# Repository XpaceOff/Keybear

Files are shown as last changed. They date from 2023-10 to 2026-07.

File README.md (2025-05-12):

# Keybear

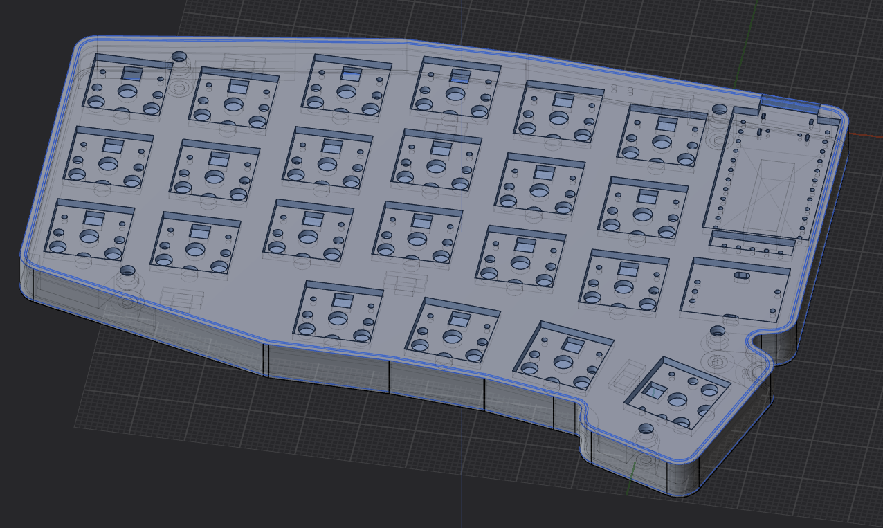
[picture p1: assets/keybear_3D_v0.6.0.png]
Keybear 3D Model


## Directory Structure

- firmware: contain files to setup the firmware of the board.
  - kmk: [kmk firmware](https://github.com/KMKfw/kmk_firmware) config files.
- keybear-chocolate: all files used to create the chocolate version of the board.
  - case:
    - gcode_and_obj: Files used to print the case
    - plasticity_archive: old versions of the plasticity file.
    - keybear-choco_case_slim.plasticity: Latest plasticity file.
- kicad_footprints: footprints used in my kicad projects.

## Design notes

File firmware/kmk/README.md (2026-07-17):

# Keybear KMK Firmware

This folder contains KMK firmware configurations for the Keybear keyboard.  
Each subfolder targets a specific microcontroller. The PCB and wiring are identical across all variants — only the controller and its pin names differ.

---

## PCB Pad Map

The pad numbers below refer to the physical pads on the Keybear PCB, following the standard Pro Micro pinout layout.

```
Pad 24 ── RAW              TX  ── Pad 1
Pad 23 ── GND              RX  ── Pad 2
Pad 22 ── RST              GND ── Pad 3
Pad 21 ── VCC              GND ── Pad 4
Pad 20 ── COL0             SDA ── Pad 5
Pad 19 ── COL1             SCL ── Pad 6
Pad 18 ── COL2             ROW0 ── Pad 7
Pad 17 ── COL3             ROW1 ── Pad 8
Pad 16 ── COL4             ROW2 ── Pad 9
Pad 15 ── COL5             ROW3 ── Pad 10
Pad 14 ── CS               ENCA ── Pad 11
Pad 13 ── LED              ENCB ── Pad 12
```

| Pad | Function | Notes |
|-----|---|---|
| 1 | TX | UART transmit — split comms |
| 2 | RX | UART receive — split comms |
| 3 | GND | |
| 4 | GND | |
| 5 | SDA | I2C data |
| 6 | SCL | I2C clock |
| 7 | ROW0 | Matrix row 0 |
| 8 | ROW1 | Matrix row 1 |
| 9 | ROW2 | Matrix row 2 |
| 10  | ROW3 | Matrix row 3 |
| 11  | ENCA | Rotary encoder pin A |
| 12  | ENCB | Rotary encoder pin B |
| 13  | LED | RGB data line |
| 14  | CS | |
| 15  | COL5 | Matrix column 5 |
| 16  | COL4 | Matrix column 4 |
| 17  | COL3 | Matrix column 3 |
| 18  | COL2 | Matrix column 2 |
| 19  | COL1 | Matrix column 1 |
| 20  | COL0 | Matrix column 0 |
| 21  | VCC | 3.3 V power |
| 22  | RST | Reset |
| 23  | GND | |
| 24  | RAW | Battery / unregulated power input |

---

## Controller Variants

| Folder | Controller | Split | BLE |
|---|---|---|-----|
| [`blok/`](blok/) | Boardsource BLOK (RP2040) | Wired UART | No |
| [`nice_nano/wired/`](nice_nano/wired/) | nice!nano v2 (nRF52840) | Wired UART | No |
| [`nice_nano/wireless/`](nice_nano/wireless/) | nice!nano v2 (nRF52840) | BLE | Yes |
| [`nice_nano/wired/mix/`](nice_nano/wired/mix/) | nice!nano (left) + BLOK (right) | Wired UART | No |

---

## BLOK Setup

- Install CircuitPython [v8.2.6](https://adafruit-circuit-python.s3.amazonaws.com/bin/boardsource_blok/en_US/adafruit-circuitpython-boardsource_blok-en_US-8.2.6.uf2)
- Get a KMK copy of this [commit 5525233](https://github.com/KMKfw/kmk_firmware/archive/5525233cb957c367e4f0b589abcaeb1b5da53ec0.zip)

For nice!nano variants see the README inside the relevant subfolder.

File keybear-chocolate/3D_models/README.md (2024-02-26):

Here are the *.step files I import into plasticity to then create the case.

The first time I did this, I can export the STEP file from Kicad directly
but last time I tried I had many issues with the format. If that fails then
you could use Freecad to export the STEP file. 

Here are the two ways to export the STEP file:

## From Kicad directly
Go to `File` > `Export` > `STEP...` and select this directory

## From Freecad
- Install Freecad.
- Install the plugin called `StepUp Workbench`. In Freecad go to `Tools` > `Addon Manager` and install it.
- Restart Freecad.
- Open the `*.kicad_pcb` file from Freecad.
- Select the PCB and export the STEP file by going to `File` > `Export...`.
When ask about export options make sure to set:
    - Units for export of STEP: Millimeter
    - Export single object placement.

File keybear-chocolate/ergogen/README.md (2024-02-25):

I downloaded Ergogen in a folder called `tmp` in the upper directory.

projects
  |-- tmp
  | |-- ergogen
  |-- Keybear

to compile the Kicad files from the Ergogen config file I do:

```bash
cd Keybear

# For PCB
node ..\tmp\ergogen\src\cli.js keybear-chocolate\ergogen\ -o keybear-chocolate\ergogen\out\PCB

# For Plate
node ..\tmp\ergogen\src\cli.js keybear-chocolate\ergogen\ -o keybear-chocolate\ergogen\out\Plate
```

> [!Note] 
> To generate the plate you will need to change the value of `pcbs.keybear.outlines.main.outline`
> to `combo`. Generate the plate and remember to set it back to `plate`

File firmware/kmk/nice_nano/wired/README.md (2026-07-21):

# Keybear — nice!nano v2 Wired Setup

This folder contains KMK firmware files for the Keybear keyboard using two **nice!nano v2** controllers connected via a **USB cable** (wired UART split). This is a custom feature of the Keybear PCB design — the inter-half USB connector replaces the TRRS jack found on most split keyboards. The keyboard connects to your PC over USB-C.

---

## Requirements

- 2× nice!nano v2
- 1× USB cable for the split connection between the two halves (custom PCB connector)
- CircuitPython **8.x or higher** (nRF52840 build)
- KMK firmware (must be **pre-compiled** — see below)
- USB-C cable (to connect left half to PC)

---

## Step 1 — Install CircuitPython on both halves

1. Download CircuitPython **8.2.6** for the nice!nano (the tested and recommended version):  
   https://adafruit-circuit-python.s3.amazonaws.com/bin/nice_nano/en_US/adafruit-circuitpython-nice_nano-en_US-8.2.6.uf2  
   *(Other versions are listed at https://circuitpython.org/board/nice_nano/ but 8.2.6 is known to work reliably with this setup.)*

2. Put the nice!nano into bootloader mode by **double-tapping the reset button**.  
   A drive called `NICENANO` appears.

3. Drag and drop the `.uf2` file onto the `NICENANO` drive.  
   The board reboots and a `CIRCUITPY` drive appears.

4. Repeat for the second half.

---

## Step 2 — Rename the drives (required for auto-handedness)

KMK detects which half is left or right by reading the drive name. The left drive name must end in `L` and the right in `R`.

With the nice!nano connected via USB, the `CIRCUITPY` drive will appear in your file manager. Rename it directly from your OS:

- **Windows:** right-click the drive in Explorer → **Rename** → type `KEYBEAR_L` (left) or `KEYBEAR_R` (right).
- **macOS:** click the drive on the Desktop or in Finder → press **Return** → type the new name.
- **Linux:** rename via your file manager or with `mlabel` / `udisksctl`.

Repeat for the second half with the opposite name.

---

## Step 3 — Pre-compile KMK (required for nice!nano)

The nice!nano has limited flash memory. KMK must be compiled to `.mpy` bytecode before copying.

### Option A — Download pre-compiled KMK

1. Go to: https://github.com/KMKfw/kmk_firmware/actions/workflows/compile.yml
2. Click the latest successful build.
3. Download the artifact ZIP at the bottom of the page.
4. Unzip it — you will get a `kmk/` directory containing `.mpy` files.

### Option B — Compile KMK yourself

1. Download `mpy-cross` **8.2.6** matching your OS:
   - **Windows:** https://adafruit-circuit-python.s3.amazonaws.com/bin/mpy-cross/windows/mpy-cross-windows-8.2.6.static.exe
   - **Linux (x86-64):** https://adafruit-circuit-python.s3.amazonaws.com/bin/mpy-cross/linux-amd64/mpy-cross-linux-amd64-8.2.6.static

2. Add `mpy-cross` to your PATH:

   **Windows** — rename the file to `mpy-cross.exe` and move it to a folder already on your PATH (e.g. `C:\Windows\System32`), or add its folder to PATH via *System Properties → Environment Variables*.

   **Linux** — make the file executable, rename it, and add it to your PATH:
   ```sh
   # Make executable and rename
   chmod +x mpy-cross-linux-amd64-8.2.6.static
   mv mpy-cross-linux-amd64-8.2.6.static mpy-cross

   # Move to a directory already on PATH (e.g. /usr/local/bin)
   sudo mv mpy-cross /usr/local/bin/

   # Verify it works
   mpy-cross --version
   ```
   If you prefer not to use `sudo`, place it in `~/.local/bin/` instead and make sure that directory is on your PATH:
   ```sh
   mkdir -p ~/.local/bin
   mv mpy-cross ~/.local/bin/
   # Add to ~/.bashrc or ~/.zshrc if not already present:
   echo 'export PATH="$HOME/.local/bin:$PATH"' >> ~/.bashrc
   source ~/.bashrc
   ```

3. In the KMK repo root, run:
   ```sh
   python util/compile.py
   ```
   The compiled `.mpy` files are written to a `build/` folder created inside the KMK repo (e.g. `kmk_firmware/build/kmk/`).

> **Tip — reduce flash usage further:**  
> Only copy the KMK sub-modules you actually use.  
> Skip the contents of `kmk/extensions/` and `kmk/modules/` that are not imported in `code.py`.  
> The files imported by this config are:
> - `kmk/modules/layers.py`
> - `kmk/modules/holdtap.py`
> - `kmk/modules/split.py`
> - `kmk/modules/encoder.py`
> - `kmk/modules/cg_swap.py`
> - `kmk/modules/dynamic_sequences.py`
> - `kmk/modules/mouse_keys.py`
> - `kmk/extensions/rgb.py`
> - `kmk/extensions/lock_status.py`

---

## Step 4 — Compile the custom neopixel driver

This firmware uses a custom minimal `neopixel.py` (found in this folder) instead of the full Adafruit library, which saves significant flash space. It must be compiled to `.mpy` before copying.

From this folder, run:

```sh
mpy-cross neopixel.py
```

This produces `neopixel.mpy` in the same folder. Copy **only** the `.mpy` file to the board (not the `.py` source).

---

## Step 5 — Copy files to each half

Copy the following to the **root** of both `KEYBEARL` and `KEYBEARR` drives:

```
KEYBEARL/  (and KEYBEARR/)
├── boot.py        ← from this folder
├── kmk/           ← compiled KMK folder in `build/` (from Step 3)
├── neopixel.mpy   ← compiled in Step 4
├── kb.py          ← from this folder
└── code.py        ← from this folder
```

> **Note:** The `boot.py` in this folder disables the USB mass storage drive so the keyboard does not mount as a drive every time it is plugged in. See [Accessing the drive](#accessing-the-drive) below for how to re-enable it when you need to edit files.

---

## Step 6 — Connect the split cable and plug in USB

1. Connect the USB cable between the two halves using the inter-half connector on the PCB.

2. Plug the USB-C cable into the **left half** (the split target).

3. The keyboard should be recognised immediately as a USB HID device.

---

## Pin mapping reference

| Role | nice!nano pin | Pro Micro index |
|---|---|---|
| Column 0 | P0_31 | 19 |
| Column 1 | P0_29 | 18 |
| Column 2 | P0_02 | 17 |
| Column 3 | P1_15 | 16 |
| Column 4 | P1_13 | 15 |
| Column 5 | P1_11 | 14 |
| Row 0 | P0_22 | 6 |
| Row 1 | P0_24 | 7 |
| Row 2 | P1_00 | 8 |
| Row 3 | P0_11 | 9 |
| Encoder A | P1_04 | 10 |
| Encoder B | P1_06 | 11 |
| RGB data | P0_09 | 12 |
| UART RX | RX | 1 |
| UART TX | TX | 0 |

These indices match the `nice_nano` quickpin table in KMK:  
`kmk/quickpin/pro_micro/nice_nano.py`

---

## Troubleshooting

| Symptom | Fix |
|---|---|
| `CIRCUITPY` fills up / import error | KMK was not pre-compiled. Repeat Step 3. |
| `neopixel` import error | `neopixel.mpy` is missing. Repeat Step 4 and copy it to the drive. |
| Only one half works | Check the inter-half USB cable is seated. Plug the PC cable into the **left** half. |
| Wrong half is master | Rename drives so left ends in `L`, right in `R`. |
| Keys wrong side | Swap the drive names (`L`/`R`). |
| Keyboard not detected | Check `boot.py` is present at root of the drive. |

---

## Accessing the drive

The `boot.py` in this firmware disables USB mass storage so the keyboard never mounts as a drive during normal use. To access the `CIRCUITPY` drive for editing files:

1. While the half is **unplugged**, short the **RST pin to GND** on the nice!nano (use a wire or tweezers on the two pads).
2. While holding that short, **double-tap RST** (or briefly connect and reconnect RST to GND twice quickly).  
   The board enters the UF2 bootloader and mounts as `NICENANO`.
3. From there you can re-flash CircuitPython or copy files.  
   Alternatively, simply **remove `boot.py`** from the drive — the `CIRCUITPY` drive will appear normally on the next boot, letting you edit files as usual. Put `boot.py` back when done.

---

## Updating the keymap

Edit `code.py` on **both halves** (the keymap must be identical on each side).  
To access the drive, follow the steps in [Accessing the drive](#accessing-the-drive) above.  
After saving, CircuitPython auto-reloads — no reflashing needed.

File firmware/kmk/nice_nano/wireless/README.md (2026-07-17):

# Keybear — nice!nano v2 Wireless Setup

This folder contains KMK firmware files for the Keybear keyboard using two **nice!nano v2** controllers with a **fully wireless BLE split** — no TRRS cable between halves. The keyboard connects to your PC over Bluetooth.

> **Status:** BLE split in KMK is functional but still described as "in testing" by the KMK project.  
> For a stable, battle-tested experience use the [wired setup](../wired/README.md) first.

---

## Requirements

- 2× nice!nano v2
- 2× LiPo / Li-Ion batteries (one per half) — the nice!nano has an onboard charging circuit
- CircuitPython **8.x or higher** (nRF52840 build)
- KMK firmware (must be **pre-compiled** — see below)
- `adafruit_ble` library

---

## Step 1 — Install CircuitPython on both halves

1. Download CircuitPython **8.2.6** for the nice!nano (the tested and recommended version):  
   https://adafruit-circuit-python.s3.amazonaws.com/bin/nice_nano/en_US/adafruit-circuitpython-nice_nano-en_US-8.2.6.uf2  
   *(Other versions are listed at https://circuitpython.org/board/nice_nano/ but 8.2.6 is known to work reliably with this setup.)*

2. Put the nice!nano into bootloader mode by **double-tapping the reset button**.  
   A drive called `NICENANO` appears.

3. Drag and drop the `.uf2` file onto the `NICENANO` drive.  
   The board reboots and a `CIRCUITPY` drive appears.

4. Repeat for the second half.

---

## Step 2 — Install the adafruit_ble library

BLE HID requires the Adafruit BLE library.

1. Download the **Adafruit CircuitPython Bundle** matching your CircuitPython version:  
   https://github.com/adafruit/Adafruit_CircuitPython_Bundle/releases

2. From the bundle, copy the `adafruit_ble/` folder to the `lib/` directory on **both** halves:
   ```
   KEYBEARL/
   └── lib/
       └── adafruit_ble/
   ```

---

## Step 3 — Rename the drives (required for auto-handedness)

KMK detects which half is left or right by reading the drive name. The left drive name must end in `L` and the right in `R`.

Open a serial console (e.g. Thonny, `screen`, or PuTTY) connected to each half and run:

```python
import storage
storage.remount("/", readonly=False)
import os
os.rename("/", "KEYBEARL")   # on the left half
# os.rename("/", "KEYBEARR") # on the right half
```

Or follow the official guide:  
https://learn.adafruit.com/welcome-to-circuitpython/renaming-circuitpy

---

## Step 4 — Pre-compile KMK (required for nice!nano)

The nice!nano has limited flash memory. KMK must be compiled to `.mpy` bytecode before copying.

### Option A — Download pre-compiled KMK

1. Go to: https://github.com/KMKfw/kmk_firmware/actions/workflows/compile.yml
2. Click the latest successful build.
3. Download the artifact ZIP at the bottom of the page.
4. Unzip it — you will get a `kmk/` directory with `.mpy` files.

### Option B — Compile KMK yourself

1. Download `mpy-cross` **8.2.6** matching your OS:
   - **Windows:** https://adafruit-circuit-python.s3.amazonaws.com/bin/mpy-cross/windows/mpy-cross-windows-8.2.6.static.exe
   - **Linux (x86-64):** https://adafruit-circuit-python.s3.amazonaws.com/bin/mpy-cross/linux-amd64/mpy-cross-linux-amd64-8.2.6.static

2. Add `mpy-cross` to your PATH:

   **Windows** — rename the file to `mpy-cross.exe` and move it to a folder already on your PATH (e.g. `C:\Windows\System32`), or add its folder to PATH via *System Properties → Environment Variables*.

   **Linux** — make the file executable, rename it, and add it to your PATH:
   ```sh
   # Make executable and rename
   chmod +x mpy-cross-linux-amd64-8.2.6.static
   mv mpy-cross-linux-amd64-8.2.6.static mpy-cross

   # Move to a directory already on PATH (e.g. /usr/local/bin)
   sudo mv mpy-cross /usr/local/bin/

   # Verify it works
   mpy-cross --version
   ```
   If you prefer not to use `sudo`, place it in `~/.local/bin/` instead and make sure that directory is on your PATH:
   ```sh
   mkdir -p ~/.local/bin
   mv mpy-cross ~/.local/bin/
   # Add to ~/.bashrc or ~/.zshrc if not already present:
   echo 'export PATH="$HOME/.local/bin:$PATH"' >> ~/.bashrc
   source ~/.bashrc
   ```

3. In the KMK repo root, run:
   ```sh
   python util/compile.py
   ```
   The compiled `.mpy` files are written to a `build/` folder created inside the KMK repo (e.g. `kmk_firmware/build/kmk/`). Copy the `kmk/` folder from there — **not** the source `kmk/` folder at the repo root.

> **Tip — reduce flash usage:**  
> Only copy the KMK sub-modules you actually use.  
> The files imported by this config are:
> - `kmk/modules/layers.py`
> - `kmk/modules/holdtap.py`
> - `kmk/modules/split.py`
> - `kmk/modules/encoder.py`
> - `kmk/modules/cg_swap.py`
> - `kmk/modules/dynamic_sequences.py`
> - `kmk/modules/mouse_keys.py`
> - `kmk/extensions/rgb.py`
> - `kmk/extensions/lock_status.py`

---

## Step 5 — Copy files to each half

Copy the following to the **root** of both `KEYBEARL` and `KEYBEARR` drives:

```
KEYBEARL/  (and KEYBEARR/)
├── boot.py           ← from KMK repo root
├── kmk/              ← compiled KMK folder (from Step 4)
├── lib/
│   └── adafruit_ble/ ← from Step 2
├── kb.py             ← from this folder
└── code.py           ← from this folder
```

The `boot.py` is in the root of the KMK repository:  
https://github.com/KMKfw/kmk_firmware/blob/main/boot.py

---

## Step 6 — Pair with your PC

1. Power on both halves (connect batteries or USB-C for testing).

2. On your PC, open Bluetooth settings and scan for new devices.  
   You should see **"Keybear"** appear (the `ble_name` set in `code.py`).

3. Click to pair.

4. The two halves will connect to each other automatically using BLE split.  
   The half with the USB plug detected (or the one named `KEYBEARL`) acts as the BLE host.

> The keyboard advertises as `"Keybear"`. To change the name, edit the `ble_name` argument in `code.py`:
> ```python
> keyboard.go(hid_type=HIDModes.BLE, ble_name='Keybear')
> ```

---

## Battery wiring

The nice!nano v2 has a built-in LiPo charger. Connect the battery to the `BAT+` and `GND` pads on the underside of the board.

- The battery charges whenever USB is plugged in.
- To protect the battery when unused for long periods, disconnect it physically or add a power switch between `BAT+` and the board.

> **RGB and battery life:**  
> RGB LEDs consume significant power. The default brightness (`val_default`) in this config is set to `50` (out of 255).  
> For maximum battery life, reduce it further or disable RGB entirely by removing the `RGB` extension.

---

## Pin mapping reference

| Role | nice!nano pin | Pro Micro index |
|---|---|---|
| Column 0 | P0_31 | 19 |
| Column 1 | P0_29 | 18 |
| Column 2 | P0_02 | 17 |
| Column 3 | P1_15 | 16 |
| Column 4 | P1_13 | 15 |
| Column 5 | P1_11 | 14 |
| Row 0 | P0_22 | 6 |
| Row 1 | P0_24 | 7 |
| Row 2 | P1_00 | 8 |
| Row 3 | P0_11 | 9 |
| Encoder A | P1_04 | 10 |
| Encoder B | P1_06 | 11 |
| RGB data | P0_09 | 12 |

No UART data pins are needed — BLE is used for split communication.

---

## Troubleshooting

| Symptom | Fix |
|---|---|
| `CIRCUITPY` fills up / import error | KMK was not pre-compiled. Repeat Step 4. |
| Keyboard not visible to PC | Ensure `adafruit_ble` is in `lib/`. Check drive names end in `L`/`R`. |
| Only one half works | Both halves must be powered. BLE split needs both sides running. |
| Wrong half is master | Rename drives so left ends in `L`, right in `R`. |
| Keyboard disconnects randomly | Check battery level. RGB at full brightness drains batteries quickly. |
| Need to re-pair | Delete the device from your OS Bluetooth settings, then power-cycle both halves and pair again. |

---

## Updating the keymap

Edit `code.py` on **both halves** (the keymap must be identical on each side).  
After saving, CircuitPython auto-reloads — no reflashing needed.  
You can connect via USB-C to either half for editing even in wireless mode.

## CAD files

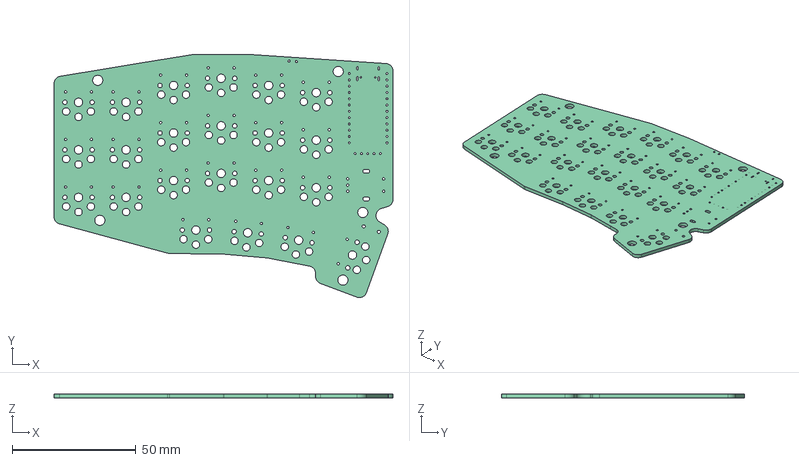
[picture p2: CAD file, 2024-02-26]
keybear-chocolate/3D_models/keybear-chocolate_v0.6.0.step
136.9 x 98.2 x 1.60 mm

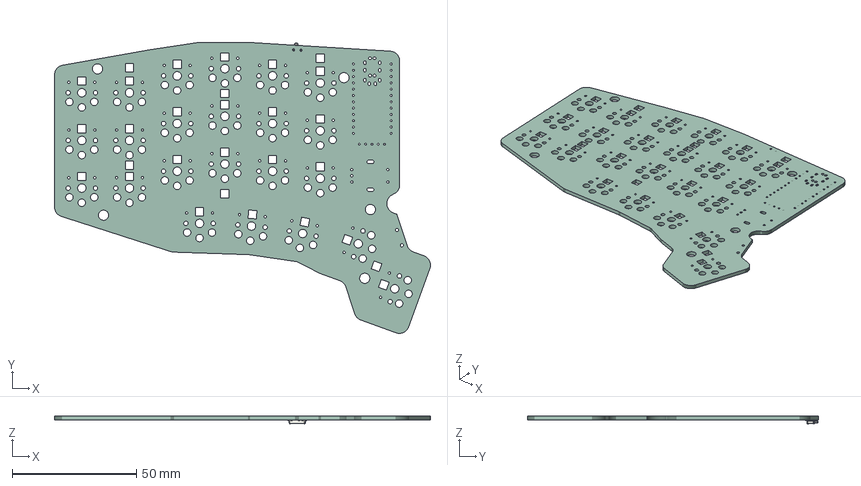
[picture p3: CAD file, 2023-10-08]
keybear-chocolate/3D_models/v0.1.0/keybear-chocolate.step
151.4 x 117.1 x 3.15 mm
_autosave-keybear-chocolate PCB

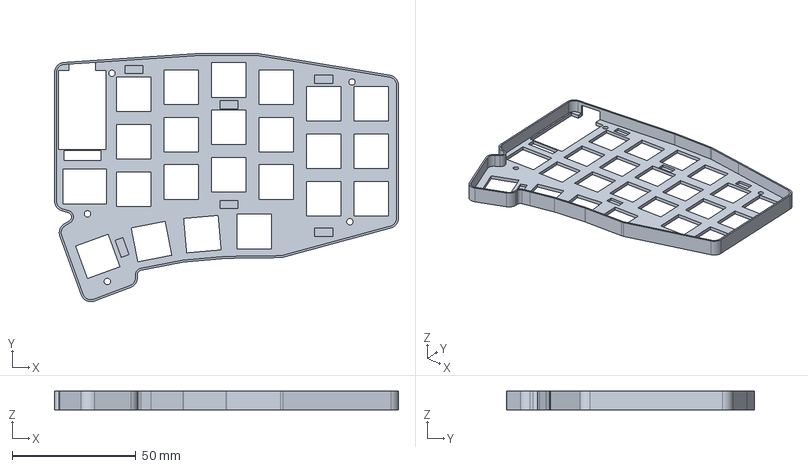
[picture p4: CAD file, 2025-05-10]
keybear-chocolate/case/gcode_and_obj/v0.6.0/keybear-choco-slim_case_L.stp
139.2 x 100.5 x 7.60 mm

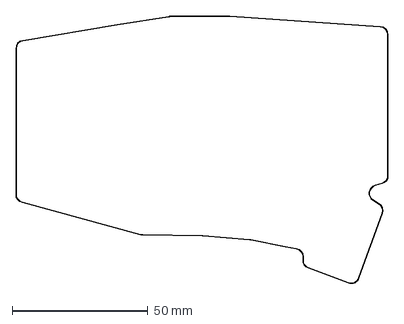
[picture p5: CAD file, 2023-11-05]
keybear-chocolate/ergogen/out/PCB/outlines/plate.dxf
136.9 x 98.3 mm

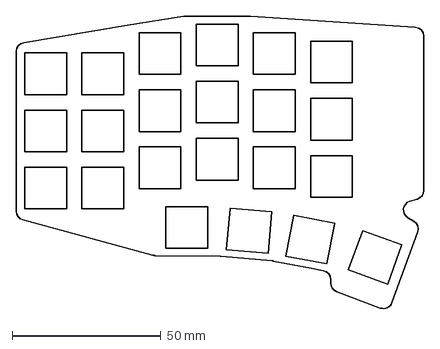
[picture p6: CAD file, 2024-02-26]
keybear-chocolate/ergogen/out/Plate/outlines/combo.dxf
136.9 x 98.3 mm

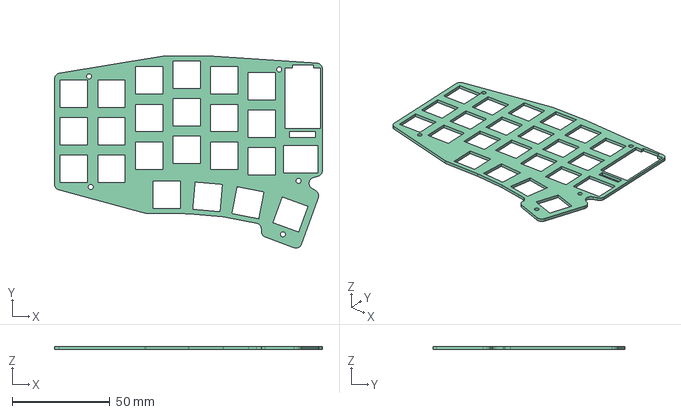
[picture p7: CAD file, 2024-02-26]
keybear-chocolate/3D_models/keybear-chocolate_plate_v0.6.0.step
136.9 x 98.2 x 1.60 mm

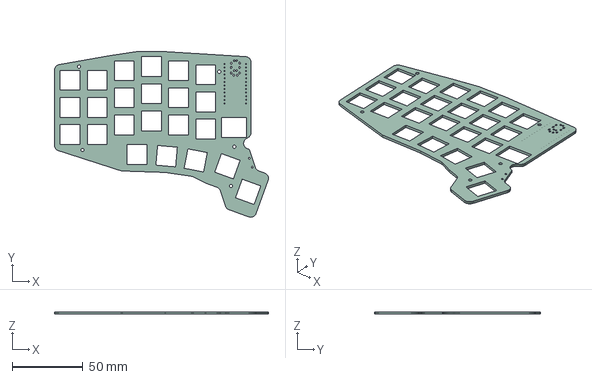
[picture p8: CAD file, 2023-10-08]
keybear-chocolate/3D_models/v0.1.0/keybear-chocolate_plate.step
151.4 x 117.1 x 1.60 mm

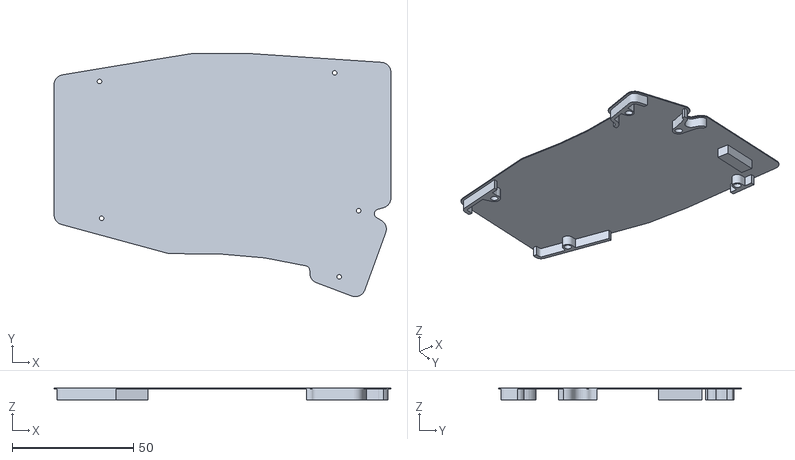
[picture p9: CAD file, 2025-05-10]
keybear-chocolate/case/gcode_and_obj/v0.6.0/keybear-choco-slim_caselid_R.obj
139.2 x 100.5 x 5.00

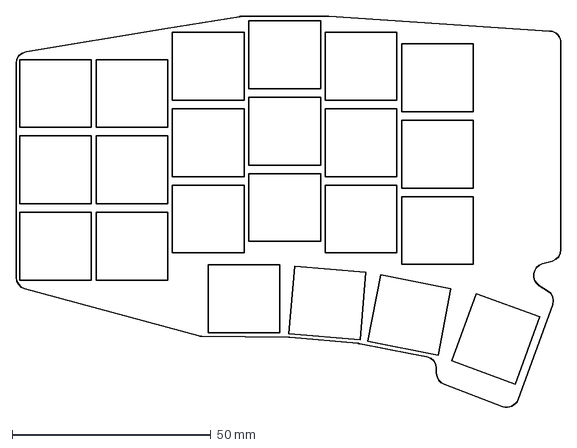
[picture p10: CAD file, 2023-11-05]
keybear-chocolate/ergogen/out/PCB/outlines/combo.dxf
136.9 x 98.3 mm

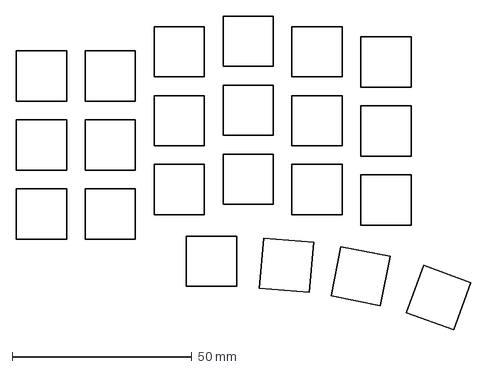
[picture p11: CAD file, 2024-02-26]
keybear-chocolate/ergogen/out/Plate/outlines/keyholes.dxf
126.6 x 87.4 mm

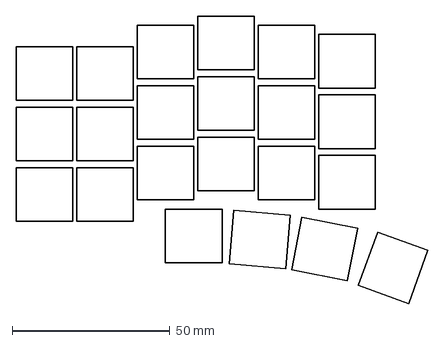
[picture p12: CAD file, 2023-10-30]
keybear-chocolate/ergogen/out/PCB/outlines/keys.dxf
130.7 x 91.2 mm

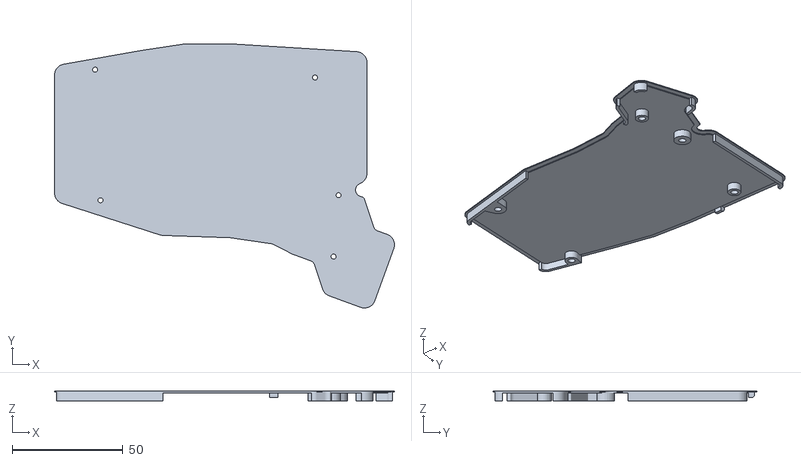
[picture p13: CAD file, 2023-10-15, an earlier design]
keybear-chocolate/case/gcode_and_obj/v0.1.0/keybear-choco-slim_caselid_R.obj
153.4 x 119.1 x 4.50

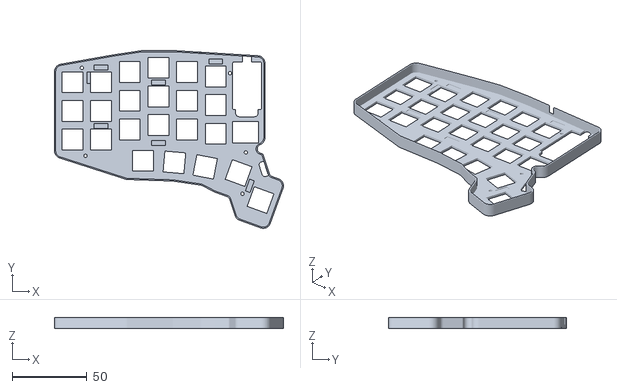
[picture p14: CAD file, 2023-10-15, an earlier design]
keybear-chocolate/case/gcode_and_obj/v0.1.0/keybear-choco-slim_case_R.obj
153.4 x 119.1 x 7.60

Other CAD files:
keybear-chocolate/case/gcode_and_obj/v0.6.0/keybear-choco-slim_caselid_L.obj
keybear-chocolate/case/gcode_and_obj/v0.6.0/keybear-choco-slim_case_R.obj
keybear-chocolate/case/gcode_and_obj/v0.1.0/keybear-choco-slim_caselid_L.obj
keybear-chocolate/case/gcode_and_obj/v0.1.0/keybear-choco-slim_case_L.obj
keybear-chocolate/case/gcode_and_obj/v0.6.0/keybear-choco-slim_case_L.obj

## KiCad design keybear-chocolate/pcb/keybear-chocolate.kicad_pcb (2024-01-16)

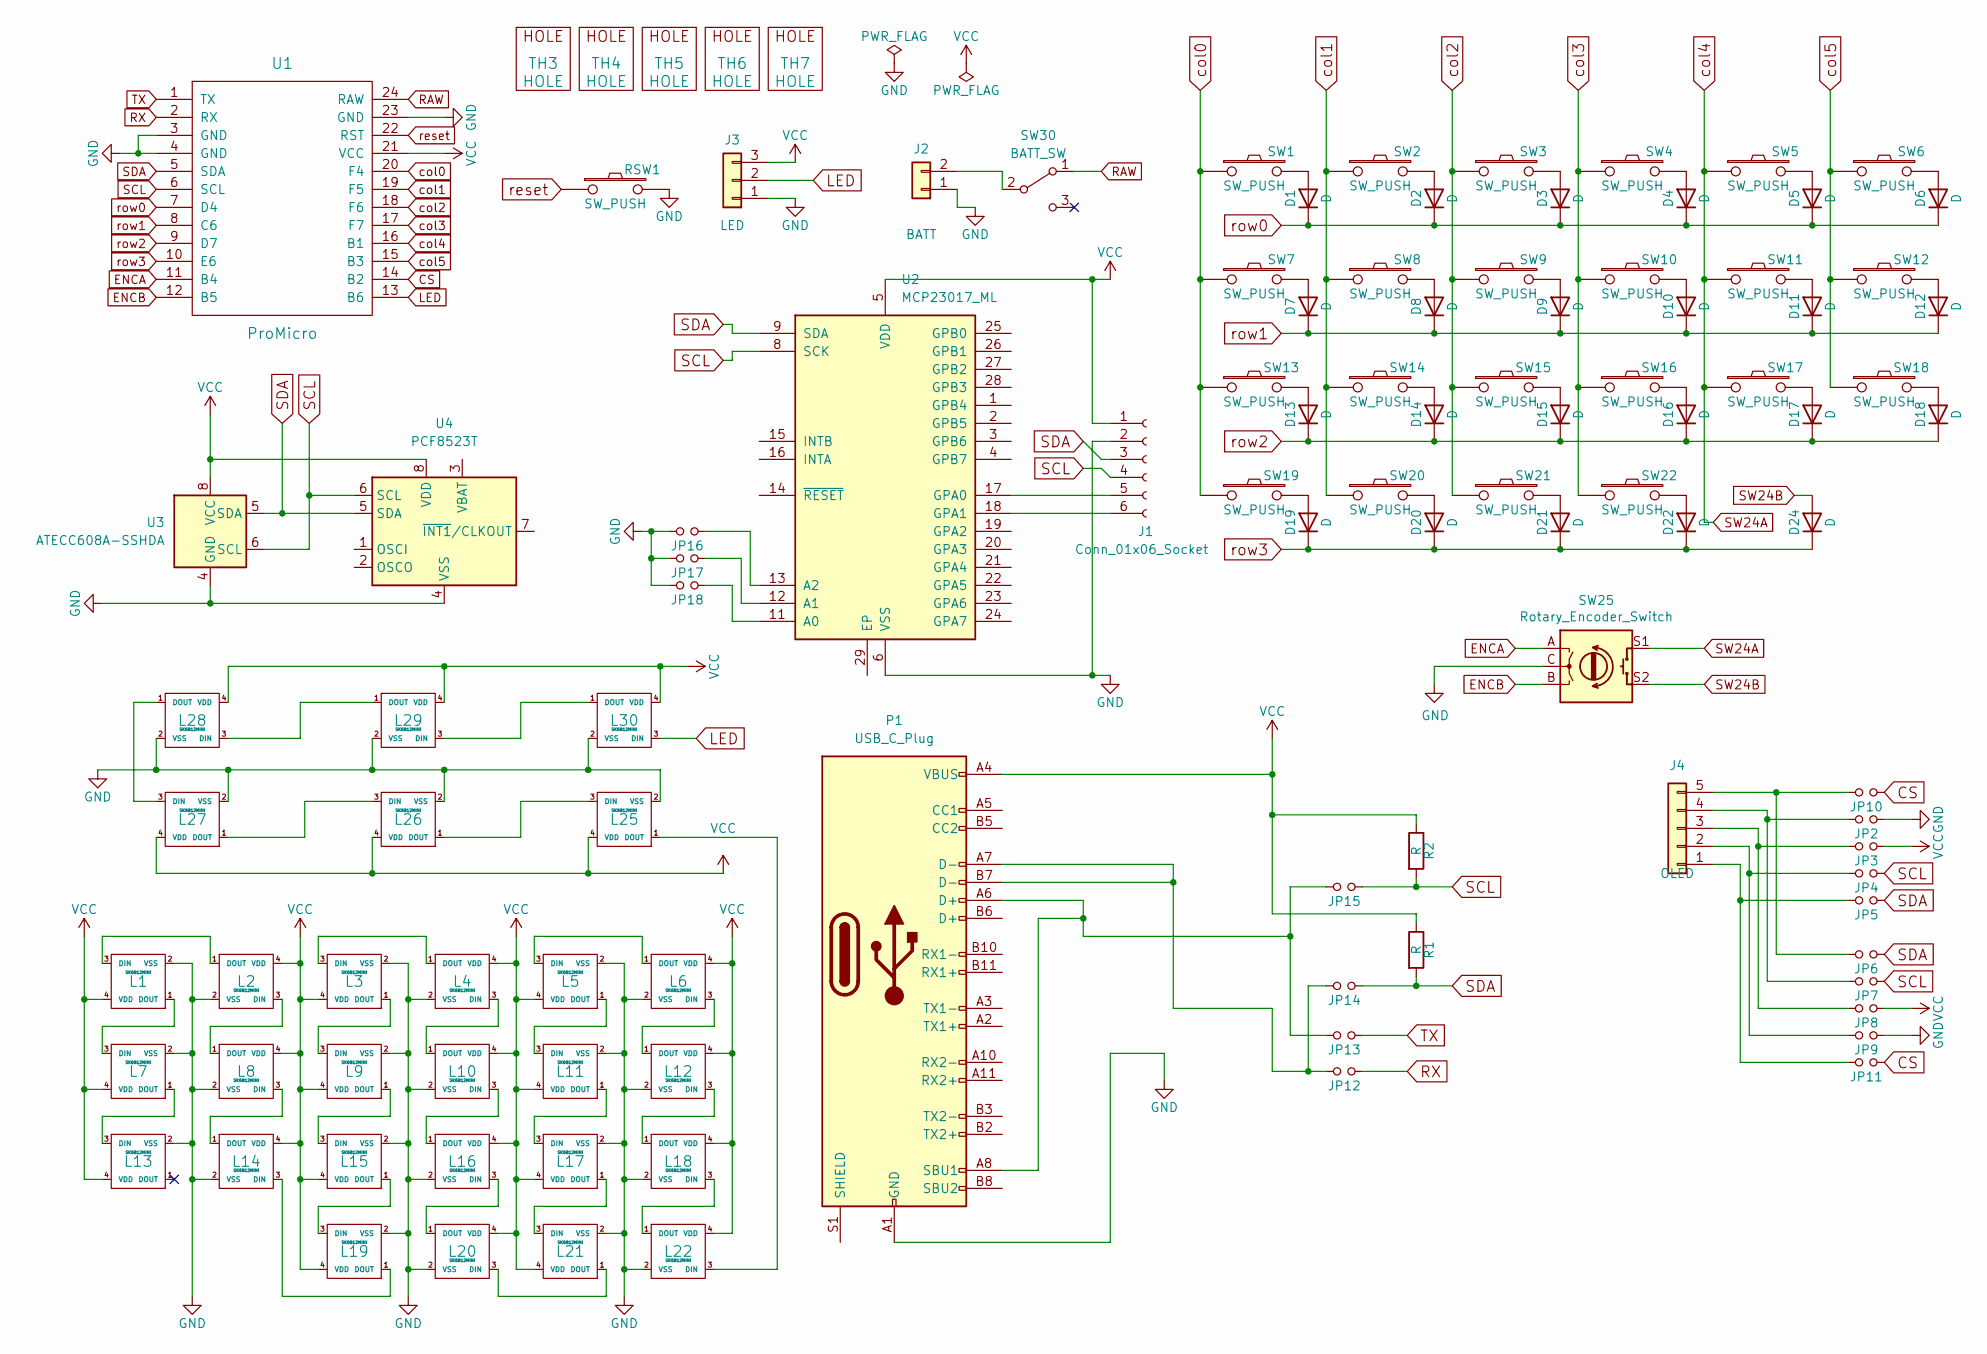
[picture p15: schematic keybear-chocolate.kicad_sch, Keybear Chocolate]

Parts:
D1, D2, D3, D4, D5, D6, D7, D8, D9, D10, D11, D12, D13, D14, D15, D16, D17, D18, D19, D20, D21, D22, D24: D; D3_SMD
J1: Conn_01x06_Socket; xo_header-0,5-6-2,5-V-SMD_1x06-1MP_P2.50mm
J2: BATT; StripBATT_xo
J3: LED; StripLED_xo
J4: OLED; OLED_xo_5pins
JP2, JP3, JP4, JP5, JP6, JP7, JP8, JP9, JP10, JP11, JP12, JP13, JP14, JP15, JP16, JP17, JP18: Jumper
L1, L2, L3, L4, L5, L6, L7, L8, L9, L10, L11, L12, L13, L14, L15, L16, L17, L18, L19, L20, L21, L22, L25, L26, L27, L28, L29, L30: SK6812MINI; SK6812MINI_xo_v02
P1: USB_C_Plug; USB_C_Receptacle_G-Switch_GT-USB-7010ASV
R1, R2: R; R_1206_3216Metric
RSW1: SW_PUSH; ResetSW
SW1, SW2, SW3, SW4, SW5, SW6, SW7, SW8, SW9, SW10, SW11, SW12, SW13, SW14, SW15, SW16, SW17, SW18, SW19, SW20, SW21: SW_PUSH; Choc_Hotswap
SW22: SW_PUSH; Choc_Hotswap_1.5u
SW25: Rotary_Encoder_Switch; RotaryEncoder_Alps_EC11E-Switch_Vertical_H20mm-keebio_modif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
SW30: BATT_SW; SW_SPDT_PCM12_2sides_xo
TH3, TH4, TH5, TH6, TH7: HOLE; HOLE_M2_TH
U1: ProMicro; ProMicro_xo
U2: MCP23017_ML; QFN-28-1EP_6x6mm_P0.65mm_EP4.25x4.25mm
U3: ATECC608A-SSHDA; SOIC-8_3.9x4.9mm_P1.27mm
U4: PCF8523T; SOIC-8_3.9x4.9mm_P1.27mm

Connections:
CS: JP10.1, JP11.1, U1.14 (B2)
ENCA: U1.11 (B4); also elsewhere on the board
ENCB: U1.12 (B5); also elsewhere on the board
GND: J1.2, J2.1, J3.1, JP2.1, JP9.1, JP16.2, JP17.2, JP18.2, L1.2 (VSS), L2.2 (VSS), L3.2 (VSS), L4.2 (VSS), L5.2 (VSS), L6.2 (VSS), L7.2 (VSS), L8.2 (VSS), L9.2 (VSS), L10.2 (VSS), L11.2 (VSS), L12.2 (VSS), L13.2 (VSS), L14.2 (VSS), L15.2 (VSS), L16.2 (VSS), L17.2 (VSS), L18.2 (VSS), L19.2 (VSS), L20.2 (VSS), L21.2 (VSS), L22.2 (VSS), L25.2 (VSS), L26.2 (VSS), L27.2 (VSS), L28.2 (VSS), L29.2 (VSS), L30.2 (VSS), P1.A1 (GND), P1.A12 (GND), P1.B1 (GND), P1.B12 (GND), RSW1.2, U1.3 (GND), U1.4 (GND), U1.23 (GND), U2.6 (VSS), U3.4 (GND), U4.4 (VSS); also elsewhere on the board
LED: J3.2, L30.3 (DIN), U1.13 (B6)
unnamed: D1.2 (A), SW1.2
unnamed: D2.2 (A), SW2.2
unnamed: D3.2 (A), SW3.2
unnamed: D4.2 (A), SW4.2
unnamed: D5.2 (A), SW5.2
unnamed: D6.2 (A), SW6.2
unnamed: D7.2 (A), SW7.2
unnamed: D8.2 (A), SW8.2
unnamed: D9.2 (A), SW9.2
unnamed: D10.2 (A), SW10.2
unnamed: D11.2 (A), SW11.2
unnamed: D12.2 (A), SW12.2
unnamed: D13.2 (A), SW13.2
unnamed: D14.2 (A), SW14.2
unnamed: D15.2 (A), SW15.2
unnamed: D16.2 (A), SW16.2
unnamed: D17.2 (A), SW17.2
unnamed: D18.2 (A), SW18.2
unnamed: D19.2 (A), SW19.2
unnamed: D20.2 (A), SW20.2
unnamed: D21.2 (A), SW21.2
unnamed: D22.2 (A), SW22.2
unnamed: J1.5, U2.17 (GPA0)
unnamed: J1.6, U2.18 (GPA1)
unnamed: J2.2, SW30.2 (B)
unnamed: J4.1, JP5.2, JP11.2
unnamed: J4.2, JP4.2, JP9.2
unnamed: J4.3, JP3.2, JP8.2
unnamed: J4.4, JP2.2, JP7.2
unnamed: J4.5, JP6.2, JP10.2
unnamed: JP12.2, JP14.2, P1.A7 (D-), P1.B7 (D-)
unnamed: L1.3 (DIN), L2.1 (DOUT)
unnamed: L1.1 (DOUT), L7.3 (DIN)
unnamed: L2.3 (DIN), L8.1 (DOUT)
unnamed: L3.3 (DIN), L4.1 (DOUT)
unnamed: L3.1 (DOUT), L9.3 (DIN)
unnamed: L5.3 (DIN), L6.1 (DOUT)
unnamed: L10.3 (DIN), L16.1 (DOUT)
unnamed: L4.3 (DIN), L10.1 (DOUT)
unnamed: L5.1 (DOUT), L11.3 (DIN)
unnamed: L11.1 (DOUT), L17.3 (DIN)
unnamed: L12.3 (DIN), L18.1 (DOUT)
unnamed: L6.3 (DIN), L12.1 (DOUT)
unnamed: L7.1 (DOUT), L13.3 (DIN)
unnamed: L14.3 (DIN), L19.1 (DOUT)
unnamed: L8.3 (DIN), L14.1 (DOUT)
unnamed: L9.1 (DOUT), L15.3 (DIN)
unnamed: L15.1 (DOUT), L19.3 (DIN)
unnamed: L16.3 (DIN), L20.1 (DOUT)
unnamed: L17.1 (DOUT), L21.3 (DIN)
unnamed: L18.3 (DIN), L22.1 (DOUT)
unnamed: L20.3 (DIN), L21.1 (DOUT)
unnamed: L22.3 (DIN), L25.1 (DOUT)
unnamed: L25.3 (DIN), L26.1 (DOUT)
unnamed: L26.3 (DIN), L27.1 (DOUT)
unnamed: L27.3 (DIN), L28.1 (DOUT)
unnamed: L28.3 (DIN), L29.1 (DOUT)
unnamed: L29.3 (DIN), L30.1 (DOUT)
unnamed: JP13.2, JP15.2, P1.A6 (D+), P1.A8 (SBU1)
unnamed: JP18.1, U2.11 (A0)
unnamed: JP17.1, U2.12 (A1)
unnamed: JP16.1, U2.13 (A2)
RAW: SW30.1 (A), U1.24 (RAW)
RX: JP12.1, U1.2 (RX)
SCL: J1.4, JP4.1, JP7.1, JP15.1, R2.2, U1.6 (SCL), U2.8 (SCK), U3.6 (SCL), U4.6 (SCL)
SDA: J1.3, JP5.1, JP6.1, JP14.1, R1.2, U1.5 (SDA), U2.9 (SDA), U3.5 (SDA), U4.5 (SDA)
SW24A: SW5.1, SW11.1, SW17.1, U1.16 (B1); also elsewhere on the board
SW24B: D24.2 (A); also elsewhere on the board
TX: JP13.1, U1.1 (TX)
VCC: J1.1, J3.3, JP3.1, JP8.1, L1.4 (VDD), L2.4 (VDD), L3.4 (VDD), L4.4 (VDD), L5.4 (VDD), L6.4 (VDD), L7.4 (VDD), L8.4 (VDD), L9.4 (VDD), L10.4 (VDD), L11.4 (VDD), L12.4 (VDD), L13.4 (VDD), L14.4 (VDD), L15.4 (VDD), L16.4 (VDD), L17.4 (VDD), L18.4 (VDD), L19.4 (VDD), L20.4 (VDD), L21.4 (VDD), L22.4 (VDD), L25.4 (VDD), L26.4 (VDD), L27.4 (VDD), L28.4 (VDD), L29.4 (VDD), L30.4 (VDD), P1.A4 (VBUS), P1.A9 (VBUS), P1.B4 (VBUS), P1.B9 (VBUS), R1.1, R2.1, U1.21 (VCC), U2.5 (VDD), U3.8 (VCC), U4.8 (VDD)
col0: SW1.1, SW7.1, SW13.1, SW19.1, U1.20 (F4)
col1: SW2.1, SW8.1, SW14.1, SW20.1, U1.19 (F5)
col2: SW3.1, SW9.1, SW15.1, SW21.1, U1.18 (F6)
col3: SW4.1, SW10.1, SW16.1, SW22.1, U1.17 (F7)
col5: SW6.1, SW12.1, SW18.1, U1.15 (B3)
reset: RSW1.1, U1.22 (RST)
row0: D1.1 (K), D2.1 (K), D3.1 (K), D4.1 (K), D5.1 (K), D6.1 (K), U1.7 (D4)
row1: D7.1 (K), D8.1 (K), D9.1 (K), D10.1 (K), D11.1 (K), D12.1 (K), U1.8 (C6)
row2: D13.1 (K), D14.1 (K), D15.1 (K), D16.1 (K), D17.1 (K), D18.1 (K), U1.9 (D7)
row3: D19.1 (K), D20.1 (K), D21.1 (K), D22.1 (K), D24.1 (K), U1.10 (E6)

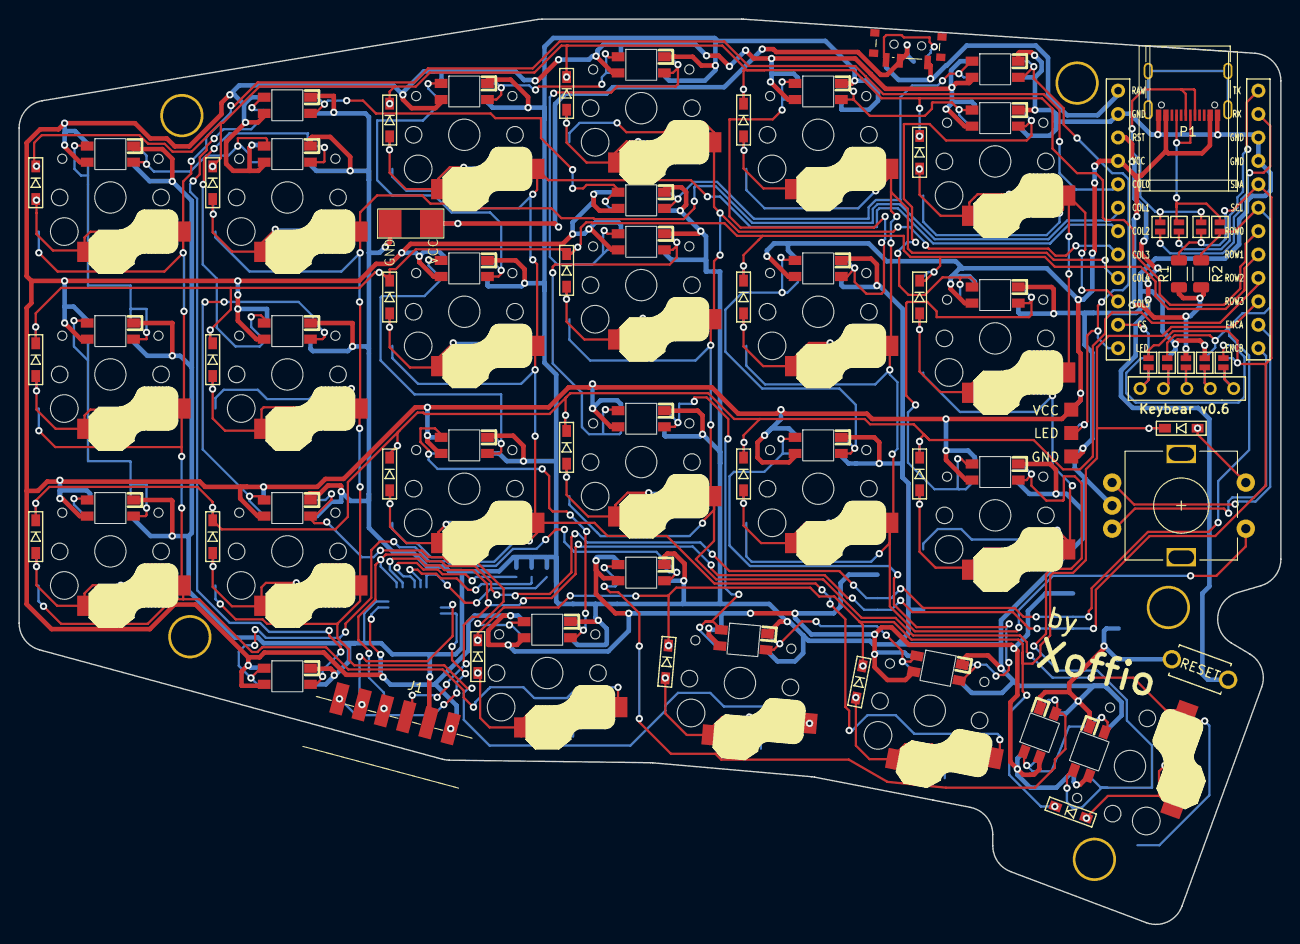
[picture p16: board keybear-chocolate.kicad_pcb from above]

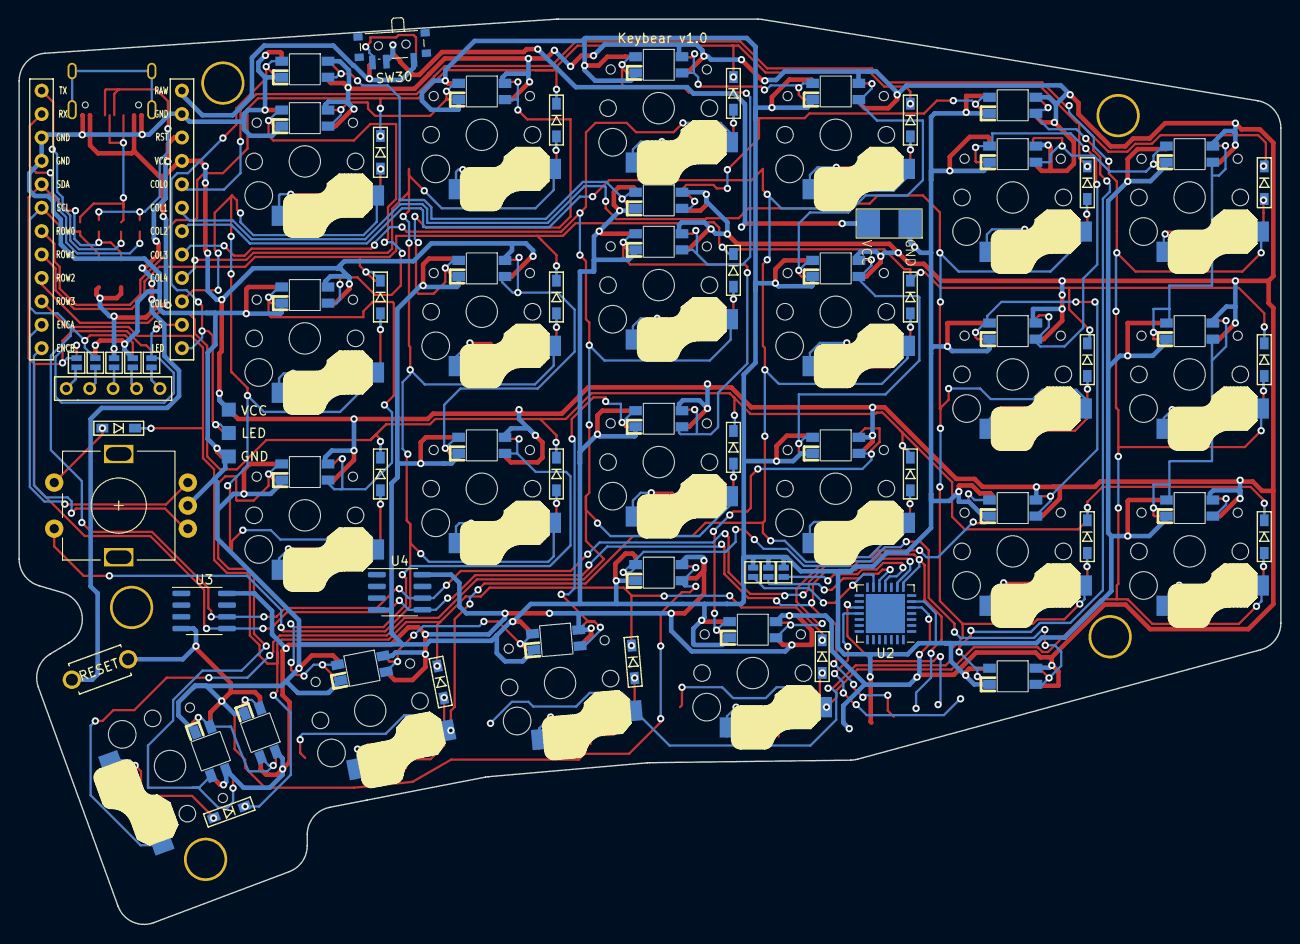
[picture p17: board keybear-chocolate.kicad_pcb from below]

Board: 2 copper layers, 136.9 x 98.2 mm, 109 parts (12 on the bottom side), 85 nets.

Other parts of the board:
SW24: Rotary_Encoder_Switch; RotaryEncoder_Alps_EC11E-Switch_Vertical_H20mm-keebio_modif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

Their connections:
ENCA: SW24.A; also elsewhere on the board
ENCB: SW24.B; also elsewhere on the board
GND: SW24.C; also elsewhere on the board
SW24A: SW24.S1; also elsewhere on the board
SW24B: SW24.S2; also elsewhere on the board

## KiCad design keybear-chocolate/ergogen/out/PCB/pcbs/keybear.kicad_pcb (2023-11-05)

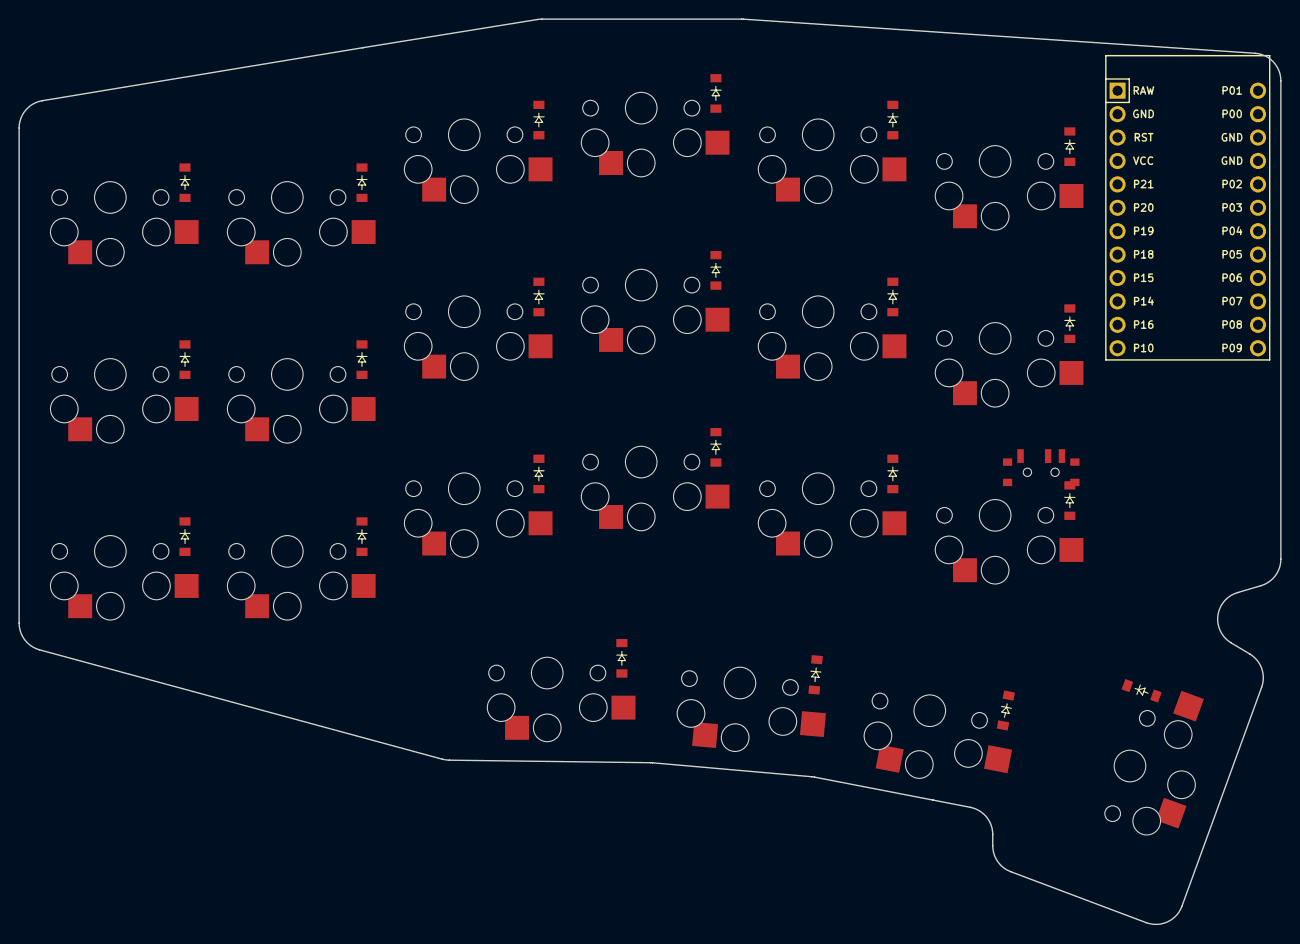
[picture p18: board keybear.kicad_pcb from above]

Board: 2 copper layers, 136.9 x 98.2 mm, 45 parts (0 on the bottom side), 23 nets, no tracks yet.

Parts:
D1, D2, D3, D4, D5, D6, D7, D8, D9, D10, D11, D12, D13, D14, D15, D16, D17, D18, D19, D20, D21, D22: ComboDiode
MCU1: ProMicro
S1, S2, S3, S4, S5, S6, S7, S8, S9, S10, S11, S12, S13, S14, S15, S16, S17, S18, S19, S20, S21, S22: PG1350

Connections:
GND: MCU1.2, MCU1.15, MCU1.16
ctrl_cluster: D20.2, S20.2
index_bottom: D13.2, S13.2
index_home: D14.2, S14.2
index_top: D15.2, S15.2
inner_bottom: D16.2, S16.2
inner_home: D17.2, S17.2
inner_top: D18.2, S18.2
layer_cluster: D21.2, S21.2
middle_bottom: D10.2, S10.2
middle_home: D11.2, S11.2
middle_top: D12.2, S12.2
opt_cluster: D19.2, S19.2
outer_bottom: D1.2, S1.2
outer_home: D2.2, S2.2
outer_top: D3.2, S3.2
pinky_bottom: D4.2, S4.2
pinky_home: D5.2, S5.2
pinky_top: D6.2, S6.2
ring_bottom: D7.2, S7.2
ring_home: D8.2, S8.2
ring_top: D9.2, S9.2
space_cluster: D22.2, S22.2

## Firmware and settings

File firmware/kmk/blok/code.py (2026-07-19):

from kb import KMKKeyboard

from kmk.keys import KC
from kmk.modules.layers import Layers as _Layers
from kmk.modules.holdtap import HoldTap
from kmk.modules.split import Split, SplitSide, SplitType
from kmk.modules.encoder import EncoderHandler
from kmk.modules.cg_swap import CgSwap as _CgSwap
from kmk.modules.dynamic_sequences import DynamicSequences
from kmk.extensions.rgb import RGB
from kmk.extensions.lock_status import LockStatus
from kmk.modules.mouse_keys import MouseKeys

# Some local variables
n_key_layer = 13          # LED position of the Layer key
n_key_cgui = 21           # LED position of the GUI/Windows key
n_key_capslock = 26       # LED position of the Capslock key 
rec_max_time = 60 * 1000  # Record max time (1 minute)
cgui_hue_vals = [220, 15] # Hue values when cgswap is disabled/enabled [win/lin, mac]

keyboard = KMKKeyboard()

# Debug Mode
keyboard.debug_enabled = False

# TODO: Comment one of these on each side
# split_side = SplitSide.LEFT
# split_side = SplitSide.RIGHT
split = Split(
    split_flip=True,                # If both halves are the same, but flipped, set this True
    # split_side=split_side,        # Sets if this is to SplitSide.LEFT or SplitSide.RIGHT, or use EE hands
    split_type=SplitType.UART,      # Defaults to UART
    split_target_left=True,         # Assumes that left will be the one on USB. Set to False if it will be the right
    uart_interval=20,               # Sets the uarts delay. Lower numbers draw more power
    data_pin=keyboard.data_pin_rx,  # The primary data pin to talk to the secondary device with
    data_pin2=keyboard.data_pin_tx, # Second uart pin to allow 2 way communication
    uart_flip=True,                 # Reverses the RX and TX pins if both are provided
    use_pio=True,
)

# Adding RGB extension
rgb = RGB(pixel_pin=keyboard.rgb_pixel_pin, num_pixels=28, hue_default=190, val_default=75)
keyboard.extensions.append(rgb)

class Layers(_Layers):
    first_boot = True  # True when keyboard first boot
    last_top_layer = 0 # Stores the last active layer
    hues = (10, 20, 69, 100, 180, 250, 35)

    def after_hid_send(self, keyboard):
        # In the LOWER layer, I have numbers and arrow keys.
        # When LOWER layer is selected, I would like go back 
        # to the DEFAULT layer if a-z or ENTER keys are pressed
        if keyboard.active_layers[0] == 1:
            for nkey in keyboard.keys_pressed:
                if nkey.code >= 4 and nkey.code <= 29 or nkey.code == 40:
                    # This is the code for KC.TO(layer)
                    self._active_combo = None
                    keyboard.active_layers.clear()
                    keyboard.active_layers.insert(0, 0)
                    break

        # This is the code that updates the color of the "layer button"
        # This code will be executed when the active layer changes OR when the keyboard first boots up
        if keyboard.active_layers[0] != self.last_top_layer or self.first_boot:
            self.first_boot = False
            self.last_top_layer = keyboard.active_layers[0]
            rgb.set_hsv(self.hues[self.last_top_layer], 255, rgb.val, n_key_layer)
            rgb.show()

keyboard.modules.append(Layers())

# React to Lock Status
class LEDLockStatus(LockStatus):
    first_boot = True # True when keyboard first boot
    def set_lock_leds(self):
        if self.get_caps_lock():
            rgb.set_hsv(100, 255, rgb.val, n_key_capslock)
        else:
            rgb.set_hsv(0, 0, 0, n_key_capslock)
        rgb.show()

    def after_hid_send(self, sandbox):
        if self.first_boot:
            self.set_lock_leds()
            self.first_boot = False

        super().after_hid_send(sandbox)  # Critically important. Do not forget
        if self.report_updated:
            self.set_lock_leds()

keyboard.extensions.append(LEDLockStatus())

# GUI Swap
class CgSwap(_CgSwap):
    last_swap_state = False
    first_boot = True

    def after_hid_send(self, keyboard):
        if self.last_swap_state != self.cg_swap_enable or self.first_boot:
            self.last_swap_state = self.cg_swap_enable
            self.first_boot = False

            this_hue = cgui_hue_vals[0]
            if self.cg_swap_enable == True:
                this_hue = cgui_hue_vals[1]

            rgb.set_hsv(this_hue, 255, rgb.val, n_key_cgui)
            rgb.show()

cg_swap = CgSwap()
keyboard.modules.append(cg_swap)

# HoldTap
holdtap = HoldTap()
keyboard.modules.append(holdtap)

# NOTE: For some reason Split needs to added after HoldTap
keyboard.modules.append(split)

# Encoder
encoder_handler = EncoderHandler()
encoder_handler.pins = ((keyboard.encoder_pin_a, keyboard.encoder_pin_b, None, False),)

# Record a sequence of keys.
dynamicSequences = DynamicSequences(
    timeout=rec_max_time, # Max time record. ms
    # use_recorded_speed = True
)

keyboard.modules.append(dynamicSequences)
RECORD = KC.RECORD_SEQUENCE()
REC_STP = KC.STOP_SEQUENCE()
REC_PLY = KC.PLAY_SEQUENCE()

keyboard.modules.append(MouseKeys())

# Cleaner key names
_______ = KC.TRNS
XXXXXXX = KC.NO

DFT_L = KC.TO(0)                    # Default Layer: set default layer. 
DFT_LS = KC.HT(KC.TO(0), KC.LSFT)   # Default Layer&Shift: Shift when pressed, and set default layer when tapped.
LRS_LS = KC.HT(KC.TG(1), KC.LSFT)   # Lower Layer&Shift: Shift when pressed, and set lower layer when tapped.
RSE_L = KC.MO(2)                    # Raise Layer: set raise layer when pressed.
RD_LL = KC.HT(KC.TO(0), KC.MO(2))   # Raise & Default Layers: Set default layer when tapped, and set raise layer when pressed.
CFG_L = KC.MO(3)                    # Config Layer: set config layer when pressed.
FUC_L = KC.MO(4)                    # Function Layer: set function layer when pressed
ARW_LE = KC.HT(KC.ENTER, KC.MO(5))

ALT_L = KC.RALT(KC.LEFT)
ALT_R = KC.RALT(KC.RIGHT)
ALT_U = KC.RALT(KC.UP)
ALT_D = KC.RALT(KC.DOWN)

RGB_TG = KC.RGB_TOG # Turn ON/OFF RGB.
RGB_BI = KC.RGB_VAI # + Brightness
RGB_BD = KC.RGB_VAD # - Brightness
RGB_SI = KC.RGB_SAI # + Saturation
RGB_SD = KC.RGB_SAD # - Saturation
RGB_HI = KC.RGB_HUI # + Hue
RGB_HD = KC.RGB_HUD # - Hue
RGB_PFX = KC.RGB_MODE_PLAIN
RGB_BFX = KC.RGB_MODE_BREATHE
RGB_RFX = KC.RGB_MODE_RAINBOW
RGB_KFX = KC.RGB_MODE_KNIGHT
RGB_SFX = KC.RGB_MODE_SWIRL

ENC_LB0 = KC.RGB_MODE_SWIRL # Encoder Left Button
ENC_LB1 = KC.RGB_VAD        # Encoder Left Button
ENC_RB0 = KC.RGB_HUI        # Encoder Right Button

# TODO: Update the 'ENC` encoder keys
# TODO: The KC.CG_TOGG is temporary. I should move it to the config layer
keyboard.keymap = [
    [ # DEFAULT LAYER
        KC.TAB,    KC.Q,    KC.W,    KC.E,    KC.R,    KC.T,                KC.Y,    KC.U,    KC.I,    KC.O,     KC.P,    KC.BSPC,\
        KC.CAPS,   KC.A,    KC.S,    KC.D,    KC.F,    KC.G,                KC.H,    KC.J,    KC.K,    KC.L,     KC.SCLN, KC.QUOT,\
        KC.LSFT,   KC.Z,    KC.X,    KC.C,    KC.V,    KC.B,                KC.N,    KC.M,    KC.COMM, KC.DOT,   KC.SLSH, KC.ESC,\
                   KC.LGUI, KC.LCTL, LRS_LS,  KC.SPACE,ENC_LB0,             ENC_RB0, ARW_LE,  RSE_L,   KC.RALT,  FUC_L,
    ],
    [ # LOWER LAYER
        _______,   KC.N1,   KC.N2,   KC.N3,   KC.N4,   KC.N5,               KC.N6,   KC.N7,   KC.N8,   KC.N9,    KC.N0,   _______,\
        _______,   _______, _______, _______, _______, _______,             KC.LEFT, KC.DOWN, KC.UP,   KC.RIGHT, _______, _______,\
        _______,   _______, _______, _______, _______, _______,             _______, _______, _______, _______,  _______, _______,\
                   _______, _______, DFT_LS,  _______, ENC_LB1,             ENC_RB0, _______, RD_LL,   _______,  _______,
    ],
    [ # RAISE LAYER
        KC.TILD,   KC.EXLM, KC.AT,   KC.HASH, KC.DLR,  KC.PERC,             KC.CIRC, KC.AMPR, KC.ASTR, KC.LPRN,  KC.RPRN, _______,\
        _______,   _______, _______, RECORD,  REC_STP, REC_PLY,             KC.MINS, KC.EQL,  KC.LBRC, KC.RBRC,  KC.BSLS, KC.GRV,\
        _______,   _______, _______, _______, _______, _______,             KC.UNDS, KC.PLUS, KC.LCBR, KC.RCBR,  KC.PIPE, KC.TILD,\
                   _______, _______, CFG_L,   _______, KC.CG_TOGG,          ENC_RB0, _______, XXXXXXX, _______,  _______,
    ],
    [ # CONFIG LAYER
        _______,   _______, _______, _______, KC.RESET,_______,             _______, _______, _______, _______,  _______, _______,\
        _______,   _______, _______, RGB_SI,  RGB_HI,  RGB_BI,              RGB_PFX, RGB_BFX, RGB_RFX, RGB_KFX,  RGB_SFX, _______,\
        _______,   _______, _______, RGB_SD,  RGB_HD,  RGB_BD,              RGB_TG,  _______, _______, _______,  _______, _______,\
                   _______, _______, XXXXXXX, _______, KC.CG_TOGG,          _______, _______, _______, _______,  _______,
    ],
    [ # FUNCTION LAYER
        _______,   KC.F1,   KC.F2,   KC.F3,   KC.F4,   KC.F5,               KC.F6,   KC.F7,   KC.F8,   KC.F9,    KC.F10,  KC.DELETE,\
        _______,   _______, _______, _______, _______, _______,             _______, _______, _______, _______,  _______, _______,\
        _______,   _______, _______, _______, _______, _______,             _______, _______, _______, _______,  _______, _______,\
                   _______, _______, _______, _______, _______,             _______, _______, _______, _______,  _______,\
    ],
    [ # ARROW LAYER, NOTE: This might replace the LOWER layer
        _______,    KC.N1,   KC.N2,   KC.N3,   KC.N4,   KC.N5,              KC.N6,   KC.N7,   KC.N8,   KC.N9,    KC.N0,   _______,\
        _______,   _______, _______, _______, _______, _______,             KC.LEFT, KC.DOWN, KC.UP,   KC.RIGHT, _______, _______,\
        _______,   _______, _______, _______, _______, _______,             ALT_L,   ALT_D,   ALT_U,   ALT_R,    _______, _______,\
                   _______, _______, _______, _______, _______,             _______, _______, _______, _______,  _______,\
    ],
]

encoder_handler.map = (
    ((KC.MW_UP, KC.MW_DOWN),),
)
keyboard.modules.append(encoder_handler)

if __name__ == '__main__':
    keyboard.go()

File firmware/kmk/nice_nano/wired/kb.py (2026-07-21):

import board

from kmk.kmk_keyboard import KMKKeyboard as _KMKKeyboard
from kmk.quickpin.pro_micro.nice_nano import pinout as pins
from kmk.scanners import DiodeOrientation


class KMKKeyboard(_KMKKeyboard):
    # -----------------------------------------------------------------------
    # Index reference (nice_nano quickpin):
    #   idx  6 = P0_22   idx  7 = P0_24   idx  8 = P1_00   idx  9 = P0_11
    #   idx 14 = P1_11   idx 15 = P1_13   idx 16 = P1_15   idx 17 = P0_02
    #   idx 18 = P0_29   idx 19 = P0_31
    # -----------------------------------------------------------------------
    col_pins = (pins[19], pins[18], pins[17], pins[16], pins[15], pins[14],)
    row_pins = (pins[6],  pins[7],  pins[8],  pins[9],)
    diode_orientation = DiodeOrientation.COLUMNS

    # Rotary encoder
    encoder_pin_a = pins[10]   # P1_04
    encoder_pin_b = pins[11]   # P1_06

    # RGB underglow / per-key
    rgb_pixel_pin = pins[12]   # P0_09

    # Wired UART split (custom inter-half USB cable) — hardware UART pins, no PIO needed
    data_pin    = board.RX     # pins[1]
    data_pin_tx = board.TX     # pins[0]

    # fmt: off
    coord_mapping = [
     0,  1,  2,  3,  4,  5,  29, 28, 27, 26, 25, 24,
     6,  7,  8,  9, 10, 11,  35, 34, 33, 32, 31, 30,
    12, 13, 14, 15, 16, 17,  41, 40, 39, 38, 37, 36,
        18, 19, 20, 21, 22,  46, 45, 44, 43, 42
    ]
    # fmt: on

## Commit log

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2023-09-04 updated latest kicad files
    [keybear-chocolate.kicad_pcb, keybear-chocolate.kicad_sch]
2023-09-04 OLED port updated to 5 pins
    OLED port updated to 5 pins to support NiceView! out of the box
    [keybear-chocolate.kicad_sch]
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2023-09-09 using custom footprints
    using custom footprints for leds and oled display
    [keybear-chocolate.kicad_pcb, keybear-chocolate.kicad_sch]
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2023-09-09 diodes organized and backlights set
    [keybear-chocolate.kicad_pcb]
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2023-09-10 update schematics with new batt pins footprint
    [keybear-chocolate.kicad_sch]
2023-09-10 small changes to pcb
    [keybear-chocolate.kicad_pcb]
2023-09-10 outline updated
    updated the outline to fit the promicro
    [combo.dxf, keybear-chocolate.kicad_pcb, keybear.kicad_pcb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]
2023-09-10 custom strip LED added
    [keybear-chocolate.kicad_pcb, keybear-chocolate.kicad_sch]
2023-09-10 power switch and strip batt added/mod
    [keybear-chocolate.kicad_pcb, keybear-chocolate.kicad_sch]
2023-09-11 Promicro updated and other small changes
    [keybear-chocolate.kicad_pcb, keybear-chocolate.kicad_sch]
2023-09-11 trrs i2c deleted
    i don't think i am going to need the trrs i2c communication. Using USART Half-duplex instead. It only uses one pin (data)
    [keybear-chocolate.kicad_pcb, keybear-chocolate.kicad_sch]
2023-09-12 first tracks. diodes repo
    [keybear-chocolate.kicad_pcb, keybear-chocolate.kicad_sch]
2023-09-13 key were re-arrange. more tracks added
    [keybear-chocolate.kicad_pcb, keybear-chocolate.kicad_sch]
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2023-09-21 finished with keys LEG's tracks
    [keybear-chocolate.kicad_pcb]
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2023-09-23 OLED Jumper fixed and connected
    [keybear-chocolate.kicad_pcb, keybear-chocolate.kicad_sch]
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2023-09-23 batt strip connection updated. tracks made
    [keybear-chocolate.kicad_pcb, keybear-chocolate.kicad_sch]
2023-09-23 data and batt switch connections made
    [keybear-chocolate.kicad_pcb]
2023-09-23 diodes back plate connections added
    [keybear-chocolate.kicad_pcb]
2023-09-23 some DRC errors fixed.
    Missing connectection fixed
    [keybear-chocolate.kicad_pcb]
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2023-09-23 removec LEDs holes to use the new footprint
    [keybear-chocolate.kicad_pcb]
2023-09-23 LEDs footprint updated an DRC errors fixed
    [keybear-chocolate.kicad_pcb, keybear-chocolate.kicad_sch]
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2023-09-26 adding holes to the pcb
    [keybear-chocolate.kicad_pcb, keybear-chocolate.kicad_sch]
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2023-09-27 fix thermal errors
    [keybear-chocolate.kicad_pcb]
2023-09-27 text added to the pcb
    [keybear-chocolate.kicad_pcb]
2023-09-28 set right gerber values to send to jlcpcb
    [keybear-chocolate.kicad_pcb]
2023-10-01 added initial file for the plate
    [keybear-chocolate_plate.kicad_pcb]
2023-10-01 generated Gerber files added
    [keybear-chocolate-B_Cu.gbl, keybear-chocolate-B_Mask.gbs, keybear-chocolate-B_Paste.gbp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]
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2023-10-07 added missing diode
    [keybear-chocolate.kicad_pcb]
2023-10-07 updated diode, fixed ground filled layer and other small fixes
    [keybear-chocolate.kicad_pcb, keybear-chocolate.kicad_sch]
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2023-10-08 3d models used to make the case
    [keybear-chocolate.step, keybear-chocolate_plate.step]
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2023-10-09 files for prusa added
    [keybear-choco-slim_case.3mf, keybear-choco-slim_caselid.3mf]
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2023-10-11 I don't think i will need the .3mf files
    [keybear-choco-slim_case.3mf, keybear-choco-slim_caselid.3mf]
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2023-10-12 upper right hole moved to a better position
    [keybear-chocolate.kicad_pcb]
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2023-10-15 updating case and makig the right one
    [keybear-choco-case.obj, keybear-choco-slim_case.obj, keybear-choco-slim_case_L.obj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]
2023-10-20 small firware changes.. RGB_TOG bug present
    [code.py]
2023-10-30 deleting key and making the keyboard more compact - ergogen
    [combo.dxf, keybear.kicad_pcb, keys.dxf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]
2023-10-31 changes to the pcb outline
    [combo.dxf, keybear.kicad_pcb, plate.dxf]
2023-11-05 making the pcb more compact and removing key, and other general changes
    [keybear-chocolate.kicad_pcb]
2023-11-05 small changes to the outline onthe upper side of the pcb
    [combo.dxf, keybear-chocolate.kicad_pcb, keybear.kicad_pcb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]
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2023-11-06 re-connecting one of the under RGB
    [keybear-chocolate.kicad_pcb]
2023-11-07 re-connecting more keys and leds
    [keybear-chocolate.kicad_pcb]
2023-11-08 all keys and leds re-connected
    [keybear-chocolate.kicad_pcb]
2023-11-08 reset button is back.
    reset button is back but i might removed it later. TBD
    [keybear-chocolate.kicad_pcb]
2023-11-09 reconnection of promicro pins
    [keybear-chocolate.kicad_pcb]
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2023-11-11 moving LED ping. Adding/rename RX/TX
    [keybear-chocolate.kicad_pcb, keybear-chocolate.kicad_sch]
2023-11-11 board will be able to do uart or i2c communication between boards
    [keybear-chocolate.kicad_pcb, keybear-chocolate.kicad_sch]
2023-11-13 shift tracks around TRRS to start makind a modular mini-pcb
    [keybear-chocolate.kicad_pcb]
2023-11-15 making space for the small pcb
    [keybear-chocolate.kicad_pcb]
2023-11-16 adding possible future pads
    [keybear-chocolate.kicad_pcb]
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2023-11-18 BEFORE USBC
    I decided to do usbc instead of modular, just for now, to keep it simple...
    [keybear-chocolate.kicad_pcb]
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2023-11-24 making space at the top left to add exteranl GPIO pins
    [keybear-chocolate.kicad_pcb]
2023-11-24 adding MPC23P17_ML to add the external GPIO pins
    [keybear-chocolate.kicad_sch]
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2023-11-29 creating connections for the rtc and crypto chip
    [keybear-chocolate.kicad_pcb, keybear-chocolate.kicad_sch]
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2024-02-25 Lets have two outputs. One for the pcb ^& anotherone for the plate
    [combo.dxf, keybear.kicad_pcb, keyholes.dxf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]
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2026-07-18 fix issue with nice nano
    [code.py]
2026-07-18 Fixing mem fragmentasion issue when using nice!nano
    [code.py]
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
